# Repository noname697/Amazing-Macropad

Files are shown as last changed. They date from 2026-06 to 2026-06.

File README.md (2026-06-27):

# ⌨️ Custom Manenti Macropad

This project consists of the complete development of a custom macropad keyboard, integrating the electronic circuit in **KiCad** and the case modeling in **Autodesk Fusion**.

## 📸 Project Demo

### Render / Screenshot of the Macropad Design

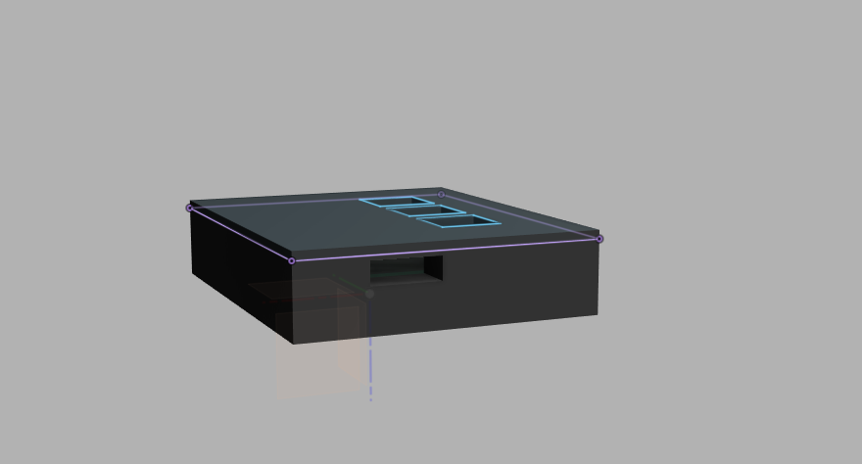
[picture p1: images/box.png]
Closed case


### Technical Drawing and 3D Modeling of the Case

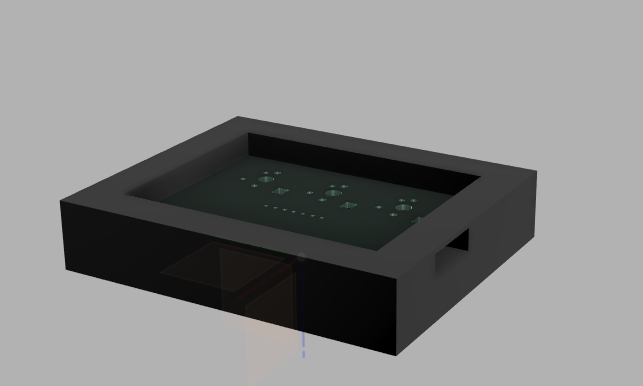
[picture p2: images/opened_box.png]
Opened case


---

## ⚡ Electronic Development (KiCad)

The circuit was designed to be compact and functional, using a microcontroller on one side of the board and the three switches on the other. The design has mounting holes strategically positioned in the four corners of the board.

### Electrical Schematic

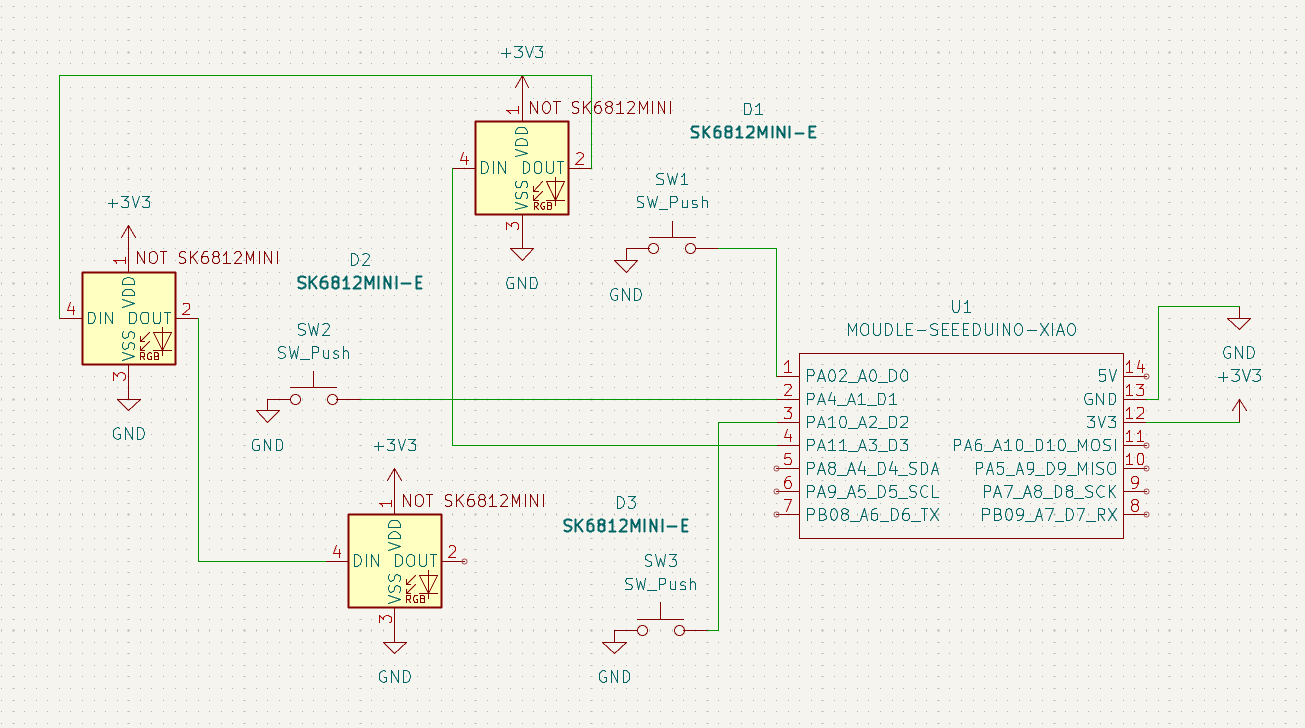
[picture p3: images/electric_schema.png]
Electrical Schematic in KiCad


### PCB Layout (Edge Cuts and Traces)

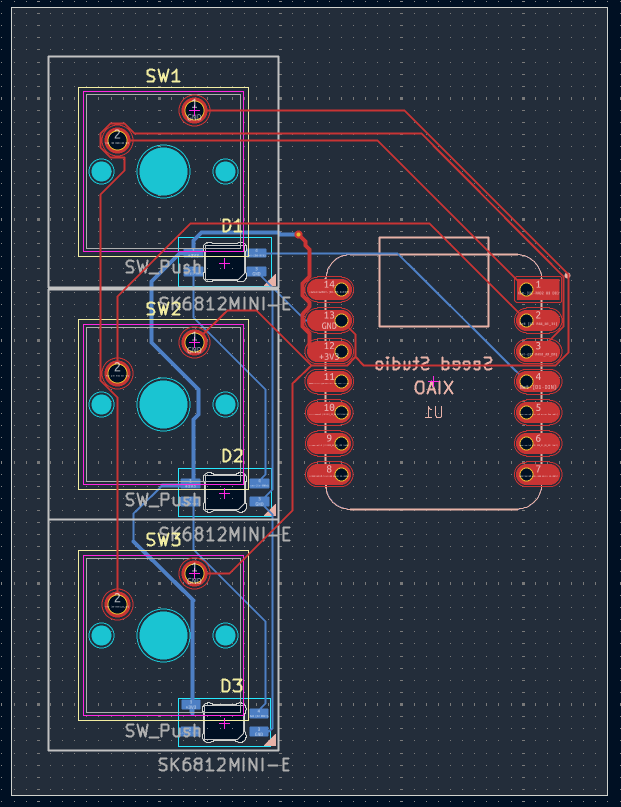
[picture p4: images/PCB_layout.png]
PCB Layout


---

## 🛠️ Case Specifications (Fusion 360)

I modeled the panel case from scratch in Fusion using the .STEP file exported from KiCad as a base to get the correct measurements; I made something simple, but functional.

- **Internal PCB tolerance:** `0.4 mm` on each side to ensure clearance during assembly.
- **Wall thickness:** `13.0 mm` for high structural and acoustic resistance.
- **Base thickness:** `3.0 mm`.
- **cut to USB:** Aligned with the physical connector.
- **Mounting:** 4 reinforcing columns at the corners of the plate (taking care not to touch any "wires") with **Ø 4.7 mm** holes for screw installation.

---

## 📦 Bill of Materials

The table below lists all components required for the complete assembly of the structure:

| Item | Component | Quantity | Description / Specification |
| :--- | :--- | :---: | :--- |
| 1 | Custom PCB | 1 | Printed circuit board developed in KiCad |
| 2 | XIAO_RP2040 microcontroller | 1 | Seeed Studio XIAO RP2040 or CircuitPython-compatible board |
| 3 | Mechanical switches | 3 | Cherry MX-style switches or compatible |
| 4 | Keycaps | 3 | Keycaps compatible with MX switches |
| 5 | LEDs | 3 | LEDs connected to pin D3 |
| 6 | Heat-set inserts | 4 | M3 × 5 × 4 mm brass inserts |
| 7 | M3 screws | 4 | M3 × 16 mm screws |
| 8 | Bottom case | 1 | 3D-printed part based on the `Bottom.STEP` file |
| 9 | Top cover / switch plate | 1 | 3D-printed part based on the `Top.STEP` file |
| 10 | USB-C cable | 1 | Cable for connecting the macropad to the computer |

---# ⌨️ Custom Tecladinho Macropad

The macropad was designed to execute quick music commands:

- Key 1: previous track
- Key 2: next track
- Key 3: pause/play

---

## ⚡ Electronic Development

The project uses a CircuitPython-compatible microcontroller and three mechanical keys for media control.

### Used pins

| Function               | Pin |
| Key 1 — previous track | D0  |
| Key 2 — next track     | D1  |
| Key 3 — play/pause     | D2  |
| LEDs                   | D3  |

The three keys are used as digital inputs in the firmware, while the LEDs are controlled by pin D3.

---

## 💻 Firmware

The firmware was developed using **KMK**, which runs on top of **CircuitPython**. This choice makes keyboard configuration easier, allowing the key behavior to be edited directly in Python.

### Main file

The main firmware must be saved on the XIAO as:

```text
main.py
```

---

## 🚀 Exporting Files for Production

The mechanical files must be exported in **.STEP** format, not STL, to preserve the CAD geometry.

### Required files

```text
Top.STEP
Bottom.STEP
```

### Exporting in Fusion 360

1. In Fusion 360, make only the part you want to export visible.
2. Hide the PCB and the other components.
3. Right-click the desired component.
4. Select **Export**.
5. Choose the **STEP** format.
6. Export each part separately:

---

## 🧠 Author

Project developed by **Arthur Lima Manenti** as a custom 3-key macropad for media control.

---

I declared the use of AI in this Readme.md to form the basis of the document, but I checked and edited everything that was inconsistent and repetitive.

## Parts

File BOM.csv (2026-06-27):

part | type | tag | number | price_per_device_CAD | description | note | provider | link
Custom PCB | custom-ordered | custom_pcb | 1 | 8.00 | 2-layer PCB fabricated from production/gerbers.zip for the 3-key macropad. | Estimated small-batch per-board cost; shipping and taxes can change. | JLCPCB | https://jlcpcb.com/
Seeed Studio XIAO RP2040 | off-the-shelf | xiao_rp2040 | 1 | 8.00 | CircuitPython-compatible microcontroller used as the keyboard controller. | Solder to the PCB using the 2.54 mm headers or castellated pads. | Seeed Studio | https://www.seeedstudio.com/Seeed-XIAO-RP2040-p-5026.html
1x7 2.54 mm male pin headers | off-the-shelf | xiao_headers | 2 | 0.50 | Headers for mounting the XIAO RP2040 to the custom PCB. | Often included with the XIAO; keep this line for funding if headers are not included. | AliExpress | https://www.aliexpress.com/w/wholesale-2.54mm-male-pin-header.html
Cherry MX-compatible mechanical switches | off-the-shelf | mx_switch | 3 | 4.50 | Three PCB-mount MX-style switches for previous, next, and play/pause keys. | Any compatible linear/tactile/clicky MX footprint switch should work. | NovelKeys | https://novelkeys.com/products/kailh-switches
MX-compatible keycaps | off-the-shelf | keycap | 3 | 3.00 | Three 1u keycaps compatible with MX-style switches. | Can be purchased as loose keycaps or from a spare set. | AliExpress | https://www.aliexpress.com/w/wholesale-mx-keycaps-1u.html
SK6812MINI-E addressable RGB LEDs | off-the-shelf | sk6812mini_e | 3 | 4.10 | Reverse-mount addressable RGB LEDs connected to D3. | Buy one small pack; only 3 LEDs are installed. | Adafruit | https://www.adafruit.com/product/4960
M3 x 5 x 4 mm brass heat-set inserts | off-the-shelf | heatset_m3 | 4 | 2.00 | Brass threaded inserts for the four internal mounting columns. | Install into the 4.7 mm blind holes in the bottom case. | AliExpress | https://www.aliexpress.com/w/wholesale-m3-5-4-heat-set-insert.html
M3 x 16 mm screws | off-the-shelf | screw_m3x16 | 4 | 1.00 | Screws used with the heat-set inserts to fasten the case/plate assembly. | Use pan-head or socket-head screws that fit the printed geometry. | AliExpress | https://www.aliexpress.com/w/wholesale-m3-16mm-screw.html
Bottom case | 3d-printed | bottom_case | 1 | 5.00 | 3D-printed bottom shell produced from production/Bottom.step. | Print in PLA/PETG or another rigid material. | Local 3D printing | production/Bottom.step
Top cover / switch plate | 3d-printed | top_cover | 1 | 4.00 | 3D-printed top switch plate produced from production/Top.step. | STEP format should be used for production export. | Local 3D printing | production/Top.step
USB-C cable | off-the-shelf | usb_c_cable | 1 | 5.00 | Cable for connecting the XIAO RP2040 macropad to a computer. | Use a data-capable USB-C cable, not charge-only. | Amazon | https://www.amazon.com/s?k=usb+c+data+cable
Solder wire | off-the-shelf | solder_wire | 1 | 1.00 | Small amount of solder for assembling the XIAO, switches, and LEDs. | Consumable estimate; omit if you already have solder. | Generic electronics supplier

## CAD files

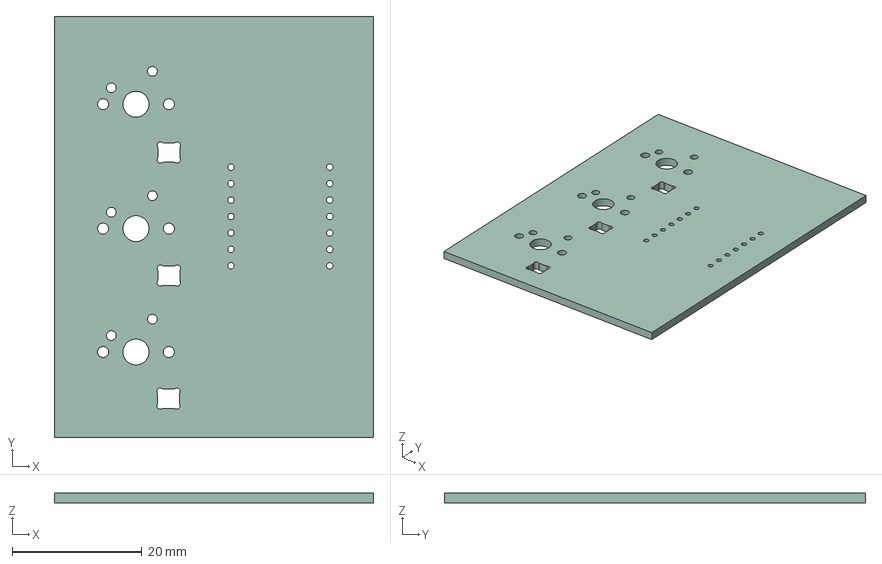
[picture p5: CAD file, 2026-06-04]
CAD/assembled-model.step
49.2 x 65.0 x 1.51 mm

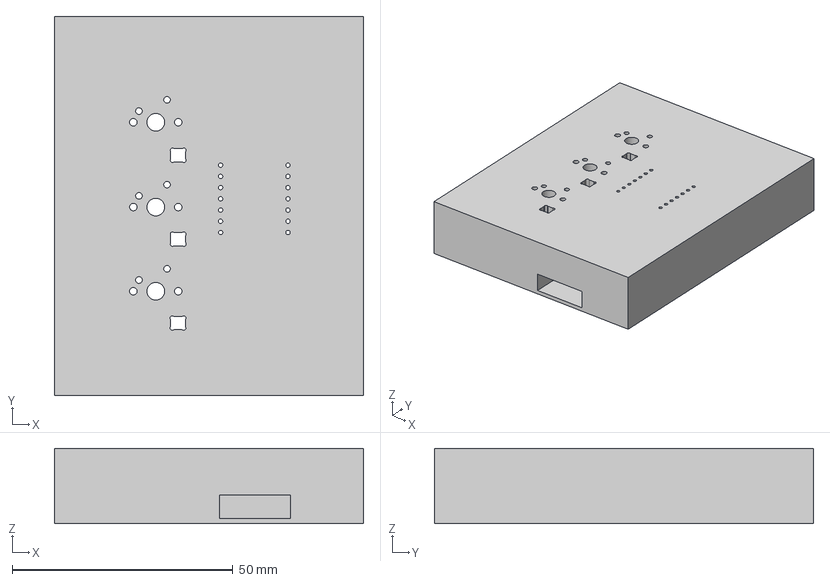
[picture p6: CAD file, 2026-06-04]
production/Bottom.step
70.1 x 85.8 x 17.0 mm

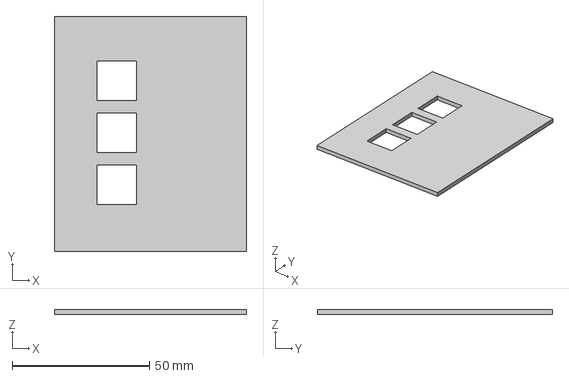
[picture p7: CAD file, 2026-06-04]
production/Top.step
70.1 x 85.8 x 2.00 mm

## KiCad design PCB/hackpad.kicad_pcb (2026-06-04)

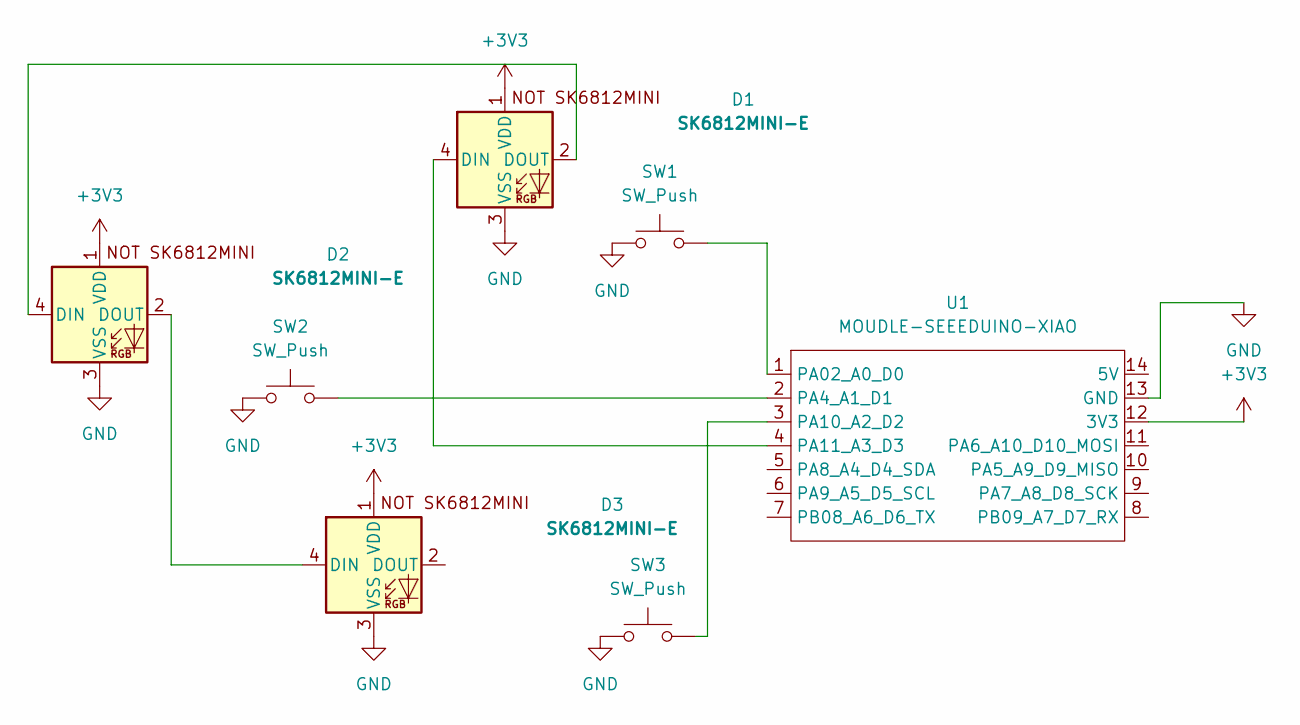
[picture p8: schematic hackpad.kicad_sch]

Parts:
D1, D2, D3: SK6812MINI-E; SK6812MINI-E_fixed
SW1, SW2, SW3: SW_Push; SW_Cherry_MX_1.00u_PCB
U1: MOUDLE-SEEEDUINO-XIAO; XIAO-Generic-Hybrid-14P-2.54-21X17.8MM

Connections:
+3V3: D1.1 (VDD), D2.1 (VDD), D3.1 (VDD), U1.12 (3V3)
GND: D1.3 (VSS), D2.3 (VSS), D3.3 (VSS), SW1.1, SW2.1, SW3.1, U1.13 (GND)
unnamed: D1.4 (DIN), U1.4 (PA11_A3_D3)
unnamed: D1.2 (DOUT), D2.4 (DIN)
unnamed: D2.2 (DOUT), D3.4 (DIN)
unnamed: SW1.2, U1.1 (PA02_A0_D0)
unnamed: SW2.2, U1.2 (PA4_A1_D1)
unnamed: SW3.2, U1.3 (PA10_A2_D2)

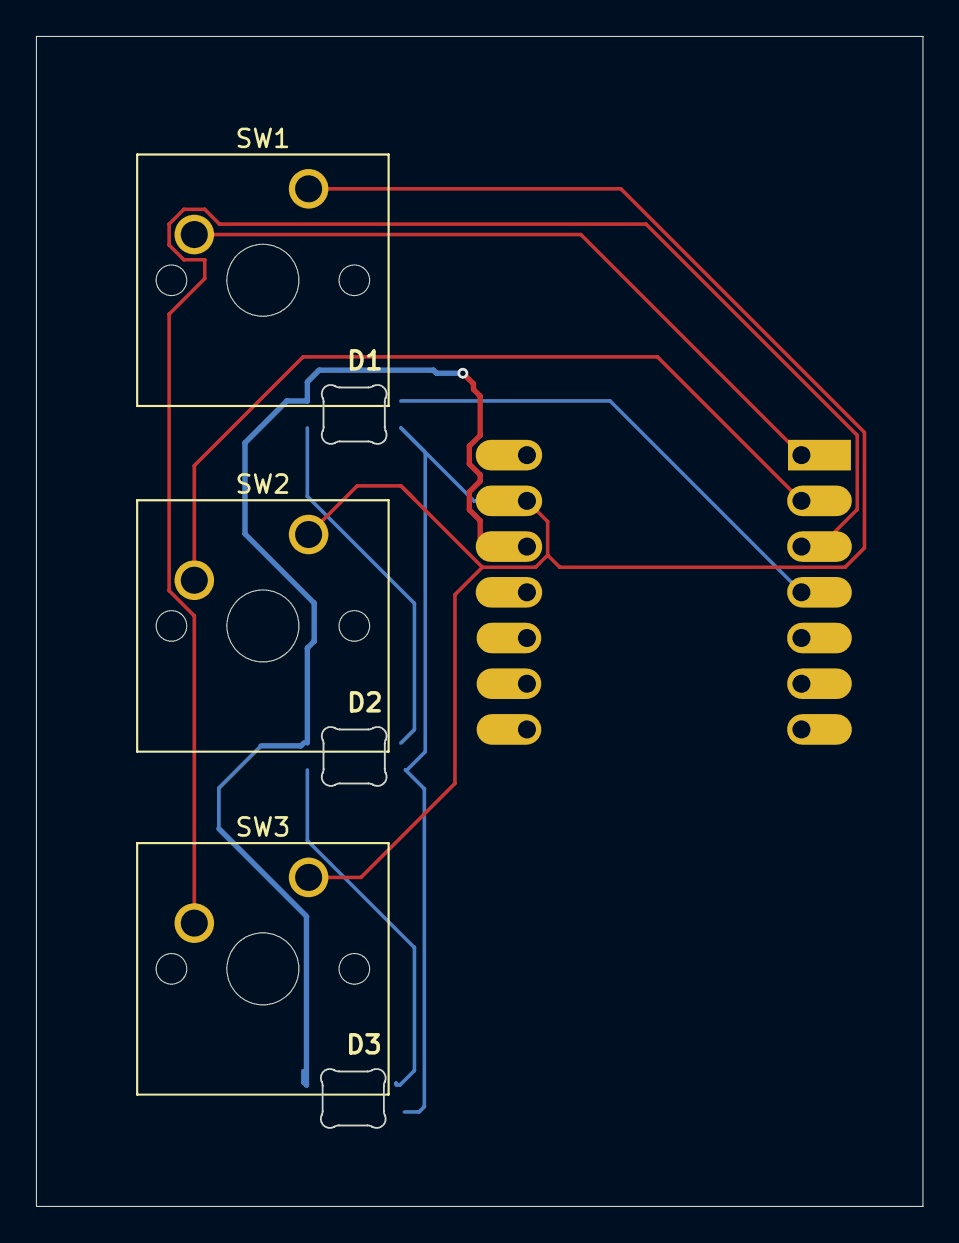
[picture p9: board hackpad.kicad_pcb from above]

Board: 2 copper layers, 49.2 x 65.0 mm, 7 parts (1 on the bottom side), 8 nets.

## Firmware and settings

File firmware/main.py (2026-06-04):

import board

from kmk.kmk_keyboard import KMKKeyboard
from kmk.keys import KC
from kmk.scanners.keypad import KeysScanner

keyboard = KMKKeyboard()

# Teclas ligadas diretamente nos pinos D0, D1 e D2
# Cada botão deve fechar contato com GND quando pressionado.
keyboard.matrix = KeysScanner(
    pins=(board.D0, board.D1, board.D2),
    value_when_pressed=False,
    pull=True,
)

# Mapa das teclas:
# Tecla 1: música anterior
# Tecla 2: próxima música
# Tecla 3: play/pause
keyboard.keymap = [
    [
        KC.MPRV,  # Previous track
        KC.MNXT,  # Next track
        KC.MPLY,  # Play/Pause
    ]
]

# LEDs na porta D3
# Esta parte é para LEDs NeoPixel/WS2812.
# Se você não estiver usando LEDs endereçáveis, pode apagar este bloco.
try:
    import neopixel

    NUM_LEDS = 3  # Altere para a quantidade real de LEDs que você colocou

    leds = neopixel.NeoPixel(
        board.D3,
        NUM_LEDS,
        brightness=0.25,
        auto_write=True,
    )

    # Cor inicial dos LEDs: azul
    leds.fill((0, 0, 255))

except Exception:
    # Se a biblioteca neopixel não estiver instalada,
    # o teclado continua funcionando normalmente.
    pass


if __name__ == "__main__":
    keyboard.go()
